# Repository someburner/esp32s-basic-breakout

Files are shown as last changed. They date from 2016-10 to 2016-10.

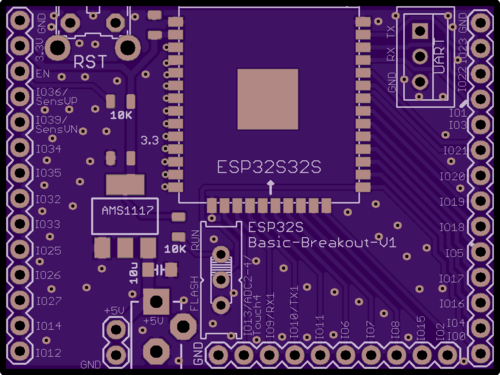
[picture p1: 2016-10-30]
rendered.png

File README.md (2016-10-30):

# ESP32S Breakout

Bare-minimum breakout board for ESP32S. Info taken from Sparkfun's [ESP32S hookup guide](https://www.sparkfun.com/news/2017). Board not yet tested, but I have tested everything in the schematic using an ESP32S with soldered connections.

# Componenents

* AI-Thinker ESP32S
* [AMS1117](https://www.amazon.com/SUNKEE-AMS1117-Voltage-Regulator-AMS1117-3-3V/dp/B00898NGL0) or similar
* 0805 Caps - 10u (x1), 22u (x1), 0.1u (x1)
* 0805 Resistors - 10K (x2)

# Connectors

* 0.1" male headers - 14x2, 10x1, 2x1 (for VIN if not using DC Jack)
* SPDT slide switch for selecting Flash/Run modes
* JST-XH 3-in connector for UART (TX0/RX0/GND)
* [Side-mount push button](http://www.digikey.com/product-search/en?keywords=1825027-5)
* [3.5mmx1.3mm DC Jack](https://www.aliexpress.com/item/DC-Power-adapter-dc-jack-connector-DC002-3-5-X-1-3-mm-50-pcs-lot/32601221205.html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)
* [2A AC Adapter](https://www.aliexpress.com/item/5-pcs-Free-Shipping-5V-DC-2A-Wall-Adapter-AC-Power-Supply-5VDC-2A-3-5mm/1048925486.html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)

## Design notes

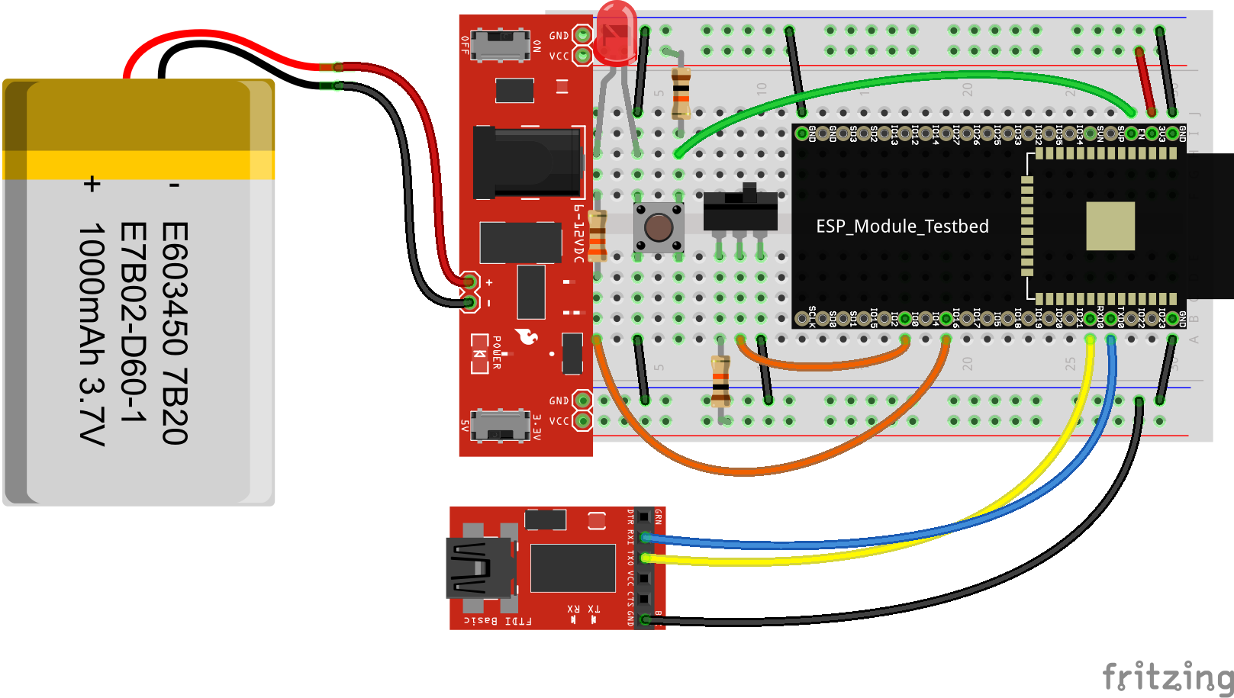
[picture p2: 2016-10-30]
sparkfun_example_hookup.png

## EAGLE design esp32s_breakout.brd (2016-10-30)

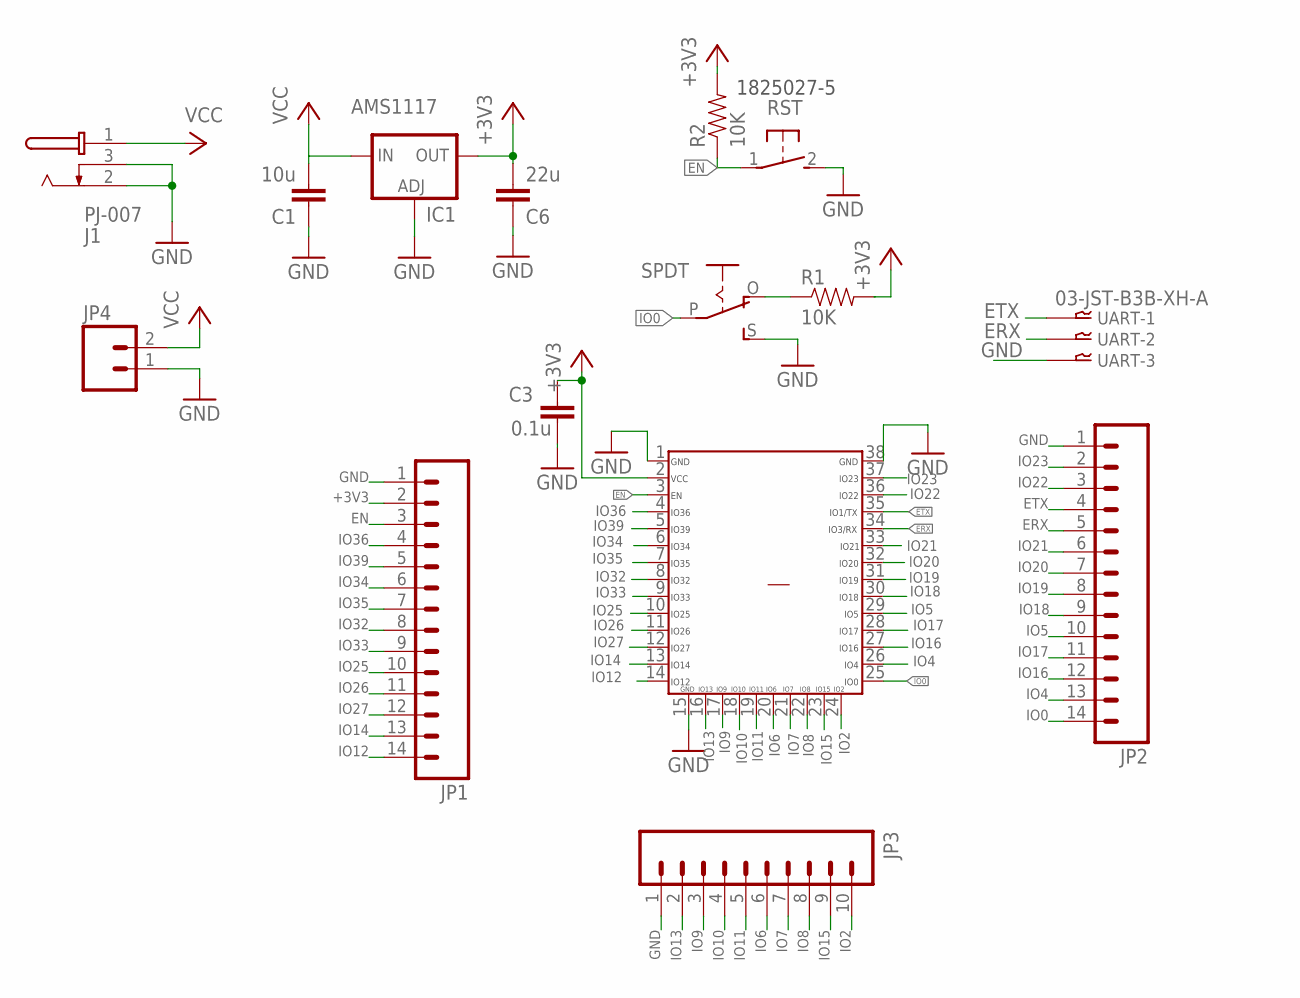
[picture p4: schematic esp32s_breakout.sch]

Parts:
C1: 10u; 0805-CAP-LARGEPADS
C3: 0.1u; 0805
C6: 22u; 0805
IC1: AMS1117; SOT223
J1: PJ-007
JP1, JP2: M14; 1X14
JP3: M10SILK_FEMALE_PTH; 1X10
JP4: M02PTH; 1X02
R1, R2: 10K; 0805
RST: 1825027-XBLK-152; 1825027-152
SPDT: EG1218S; EG1218
U$1: ESP32S32S; ESP32
UART: 03-JST-B3B-XH-A; B3B-XH

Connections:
+3V3: C3.1, C6.2, IC1.4 (OUT), JP1.2, R1.2, R2.2, U$1.2
EN: JP1.3, R2.1, RST.1, U$1.3
ERX: JP2.5, U$1.34, UART.P$2
ETX: JP2.4, U$1.35, UART.P$1
GND: C1.1, C3.2, C6.1, IC1.1 (ADJ), J1.2 (S), J1.3 (SS), JP1.1, JP2.1, JP3.1, JP4.1, RST.2 (S), SPDT.S, U$1.1, U$1.15, U$1.38, UART.P$3
IO0: JP2.14, SPDT.P, U$1.25
IO2: JP3.10, U$1.24
IO4: JP2.13, U$1.26
IO5: JP2.10, U$1.29
IO6: JP3.6, U$1.20
IO7: JP3.7, U$1.21
IO8: JP3.8, U$1.22
IO9: JP3.3, U$1.17
IO10: JP3.4, U$1.18
IO11: JP3.5, U$1.19
IO12: JP1.14, U$1.14
IO13: JP3.2, U$1.16
IO14: JP1.13, U$1.13
IO15: JP3.9, U$1.23
IO16: JP2.12, U$1.27
IO17: JP2.11, U$1.28
IO18: JP2.9, U$1.30
IO19: JP2.8, U$1.31
IO20: JP2.7, U$1.32
IO21: JP2.6, U$1.33
IO22: JP2.3, U$1.36
IO23: JP2.2, U$1.37
IO25: JP1.10, U$1.10
IO26: JP1.11, U$1.11
IO27: JP1.12, U$1.12
IO32: JP1.8, U$1.8
IO33: JP1.9, U$1.9
IO34: JP1.6, U$1.6
IO35: JP1.7, U$1.7
IO36: JP1.4, U$1.4
IO39: JP1.5, U$1.5
unnamed: R1.1, SPDT.O
P$39: U$1.GNDTHRM
VCC: C1.2, IC1.3 (IN), J1.1 (T), JP4.2

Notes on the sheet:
1825027-5

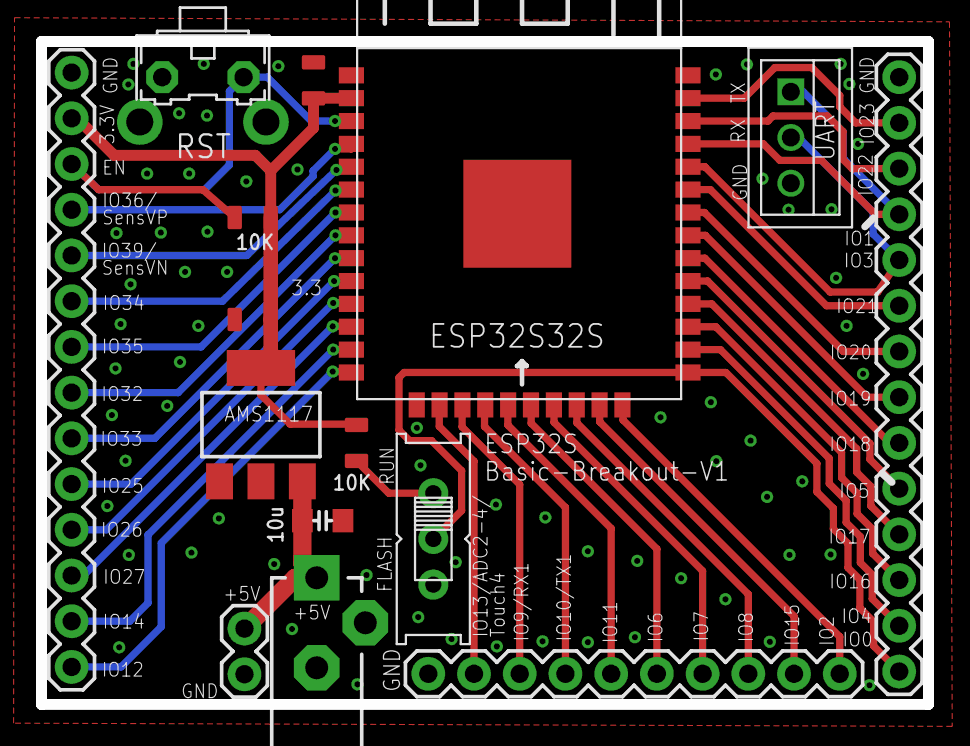
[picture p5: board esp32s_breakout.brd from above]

Board: 2 copper layers, 49.3 x 36.8 mm, 15 parts (0 on the bottom side), 38 nets.

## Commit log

2016-10-30 initial v
    [esp32s_breakout.brd, esp32s_breakout.sch]
2016-10-30 squeeze to get under 5cm
    [esp32s_breakout.brd, esp32s_breakout.sch]

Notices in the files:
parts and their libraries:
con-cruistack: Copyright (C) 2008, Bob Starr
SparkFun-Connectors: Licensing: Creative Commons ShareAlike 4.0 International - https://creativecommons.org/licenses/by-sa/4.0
